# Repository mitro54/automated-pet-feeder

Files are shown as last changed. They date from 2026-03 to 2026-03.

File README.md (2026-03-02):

# automated-pet-feeder
**This is a small personal project running on a Raspberry Pi 1 to allow pet to get some treats while the owner is away.**

The device is made out of 3D printed parts (PLA for all of the container/frame and soft TPU for the rotor to be pet safe) and uses a Raspi 1 to control the feeder. Basicly it uses an old web camera (the slot on the lid is used for mounting it) and a stepper motor to spin a 4 bladed rotor 90 degrees per run, that pushes the treats out of the container, while livestreaming and recording it. The device can be monitored and controlled via a web interface. Due to the limitation of the Raspi 1 performance, the saved "video" of the stream is actually a flipbook of images running on a loop.

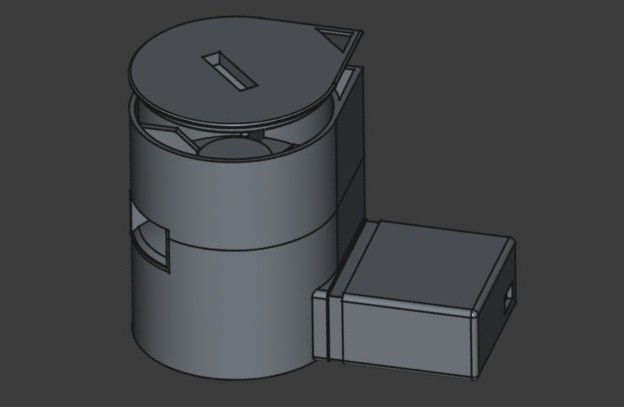
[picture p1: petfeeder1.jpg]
CAD render of the feeder


| Component | Pin Type | RPi Physical Pin | GPIO Number (BCM) |
| :--- | :--- | :--- | :--- |
| **Motor IN1** | Output | Pin 7 | GPIO 4 |
| **Motor IN2** | Output | Pin 11 | GPIO 17 |
| **Motor IN3** | Output | Pin 13 | GPIO 27 |
| **Motor IN4** | Output | Pin 15 | GPIO 22 |
| **LED Transistor Base** | Output | Pin 12 | GPIO 18 (via 1k resistor) |
| **Common Ground** | GND | Pin 6, 9, or 14 | GND |
| **Driver/LED Power** | 5V | Pin 2 or 4 | 5V |

## Setup

Here is a template for my personal setup with this, modify to fit your timezone and paths.

1. Set timezone
`sudo timedatectl set-timezone Europe/Helsinki`

2. Create systemd service
`sudo nano /etc/systemd/system/petfeeder.service`

3. Add the following content to the service file:
```bash
[Unit]
Description=Pet Feeder Controller
After=network.target
[Service]
ExecStart=/usr/bin/python3 /home/user/pet_feeder/controller.py
WorkingDirectory=/home/user/pet_feeder
User=user
Restart=always
RestartSec=5
[Install]
WantedBy=multi-user.target
```

4. Reload systemd and enable the service
`sudo systemctl daemon-reload`
`sudo systemctl enable petfeeder.service`
`sudo systemctl start petfeeder.service`

5. Check status
`sudo systemctl status petfeeder.service`

6. Make feed.sh executable
`chmod +x /home/user/pet_feeder/feed.sh`

7. Add cron job
`crontab -e`

8. Add the following content to the cron job:
```bash
0 18 * * * /home/user/pet_feeder/feed.sh >> /home/user/pet_feeder/scheduled_feeds.log 2>&1
```

9. All set up! The feeder should now run as a service automatically on startup, accessible via your local or public IP and port 8000 (depends on your setup) and the scheduled feed will be triggered at 6 PM every day by default.

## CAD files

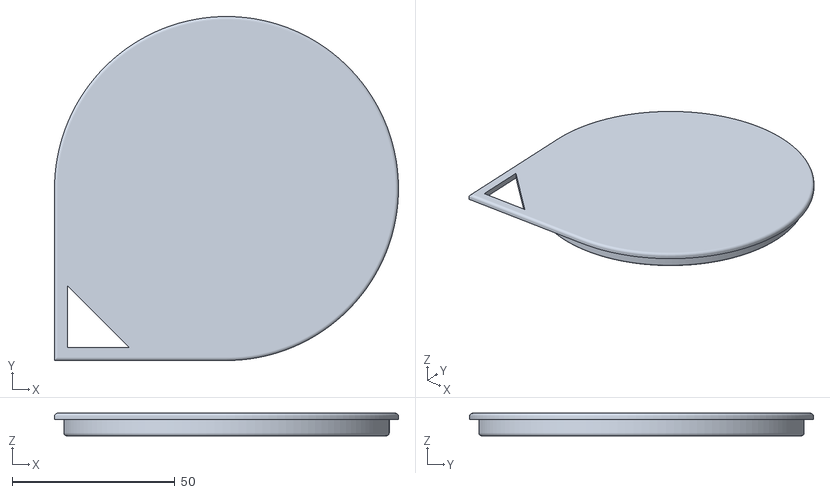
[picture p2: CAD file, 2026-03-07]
syottolaite_v1-lidv2.stl
105.7 x 105.7 x 7.00

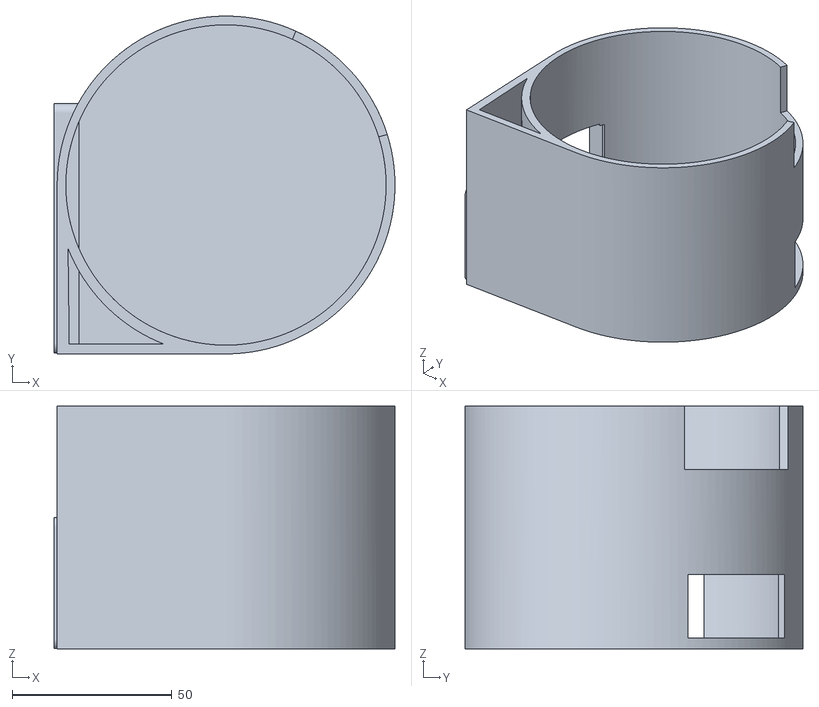
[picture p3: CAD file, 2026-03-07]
syottolaite_v1-body_bottom_Rv2.stl
106.7 x 105.7 x 76.0

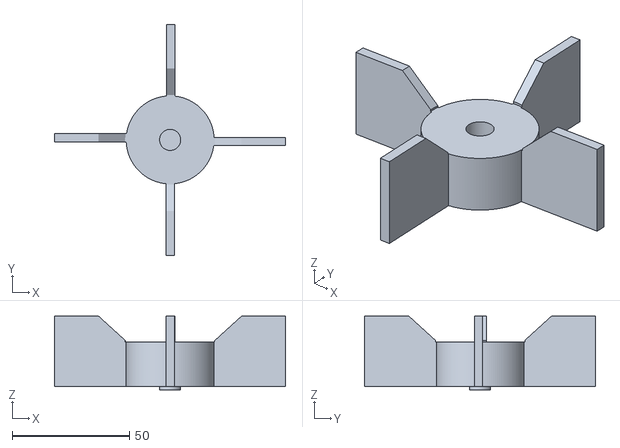
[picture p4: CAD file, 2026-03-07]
syottolaite_v1-rotorv2.stl
98.4 x 98.4 x 31.5

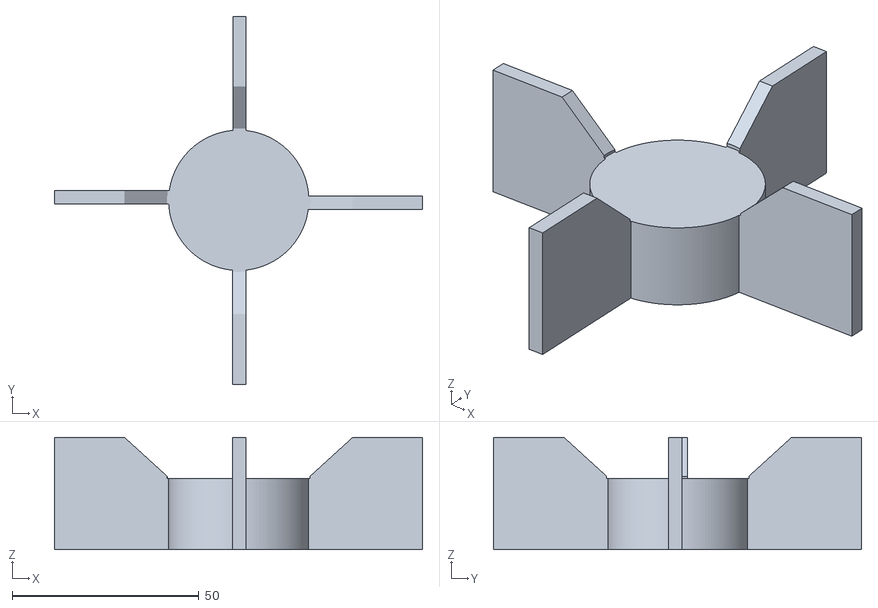
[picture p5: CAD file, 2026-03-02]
syottolaite_v1-rotor.stl
98.4 x 98.4 x 30.0

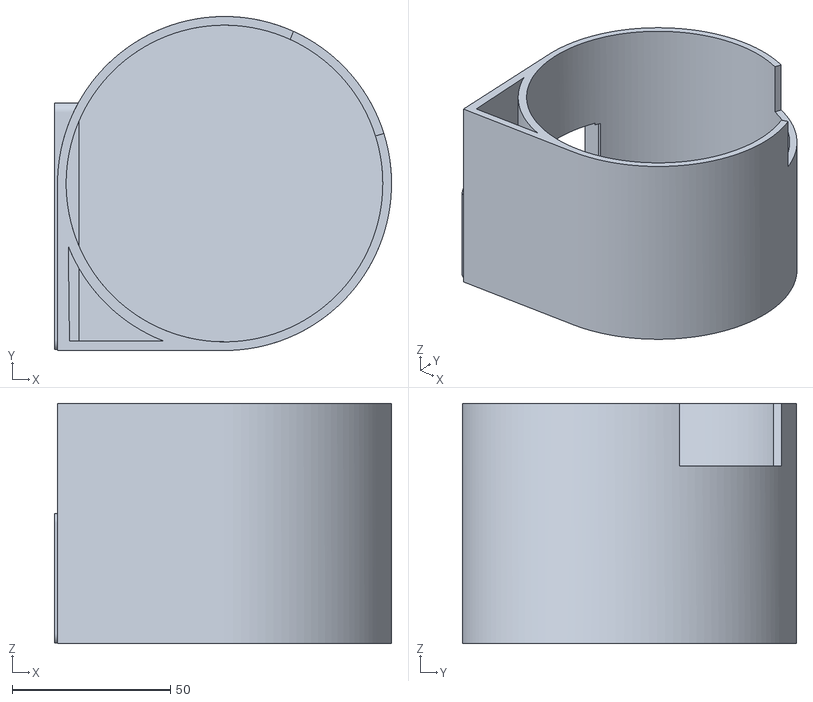
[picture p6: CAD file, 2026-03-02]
syottolaite_v1-body_bottom_R.stl
106.7 x 105.7 x 76.0

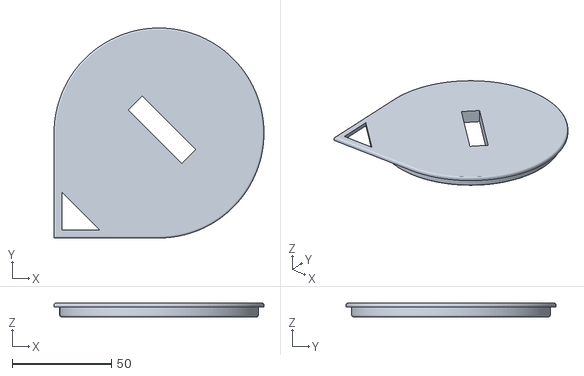
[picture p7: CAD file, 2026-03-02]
syottolaite_v1-lid.stl
105.7 x 105.7 x 7.00

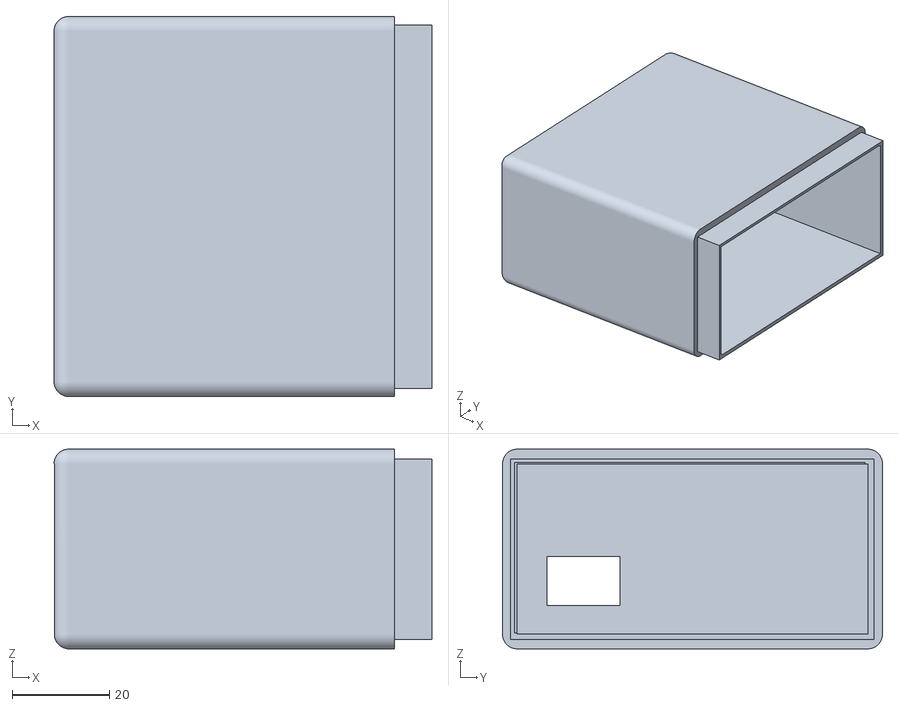
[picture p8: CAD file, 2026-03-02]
syottolaite_v1-body_bottom_L.stl
77.6 x 78.0 x 41.0

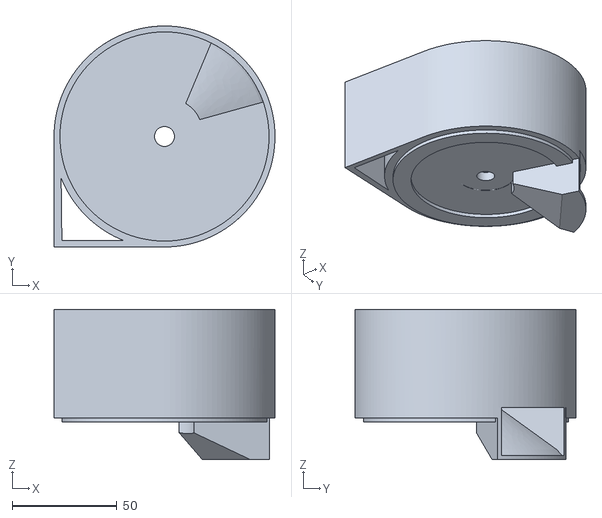
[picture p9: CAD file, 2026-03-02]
syottolaite_v1-body_top.stl
105.7 x 105.7 x 71.9

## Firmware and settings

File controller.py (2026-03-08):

"""Automated pet feeder controller.

Drives a 28BYJ-48 stepper motor (via ULN2003) and an LED indicator
directly from the Raspberry Pi GPIO.  Also serves a web UI for live
camera streaming, recording playback, and manual feed control.
"""

import hashlib
import json
import os
import secrets
import signal
import shutil
import subprocess
import threading
import time
import urllib.request

import RPi.GPIO as GPIO
from http.server import SimpleHTTPRequestHandler, HTTPServer
from socketserver import ThreadingMixIn

# ──────────────────────────────────────────────────────────────────────
# CONFIGURATION
# ──────────────────────────────────────────────────────────────────────

# Stepper motor – 28BYJ-48 via ULN2003 driver board
MOTOR_PINS = [4, 17, 27, 22]       # IN1, IN2, IN3, IN4

# LED indicator – transistor base via 1 kΩ resistor
LED_PIN = 18                        # GPIO 18

# Networking
STREAM_PORT = 8080
WEB_PORT = 8000

# File system
BASE_DIR = os.path.dirname(os.path.abspath(__file__))
STABLE_DIR = os.path.join(BASE_DIR, "stable_run")
TEMP_DIR = os.path.join(BASE_DIR, "temp_recording")
SNAPSHOT_URL = f"http://localhost:{STREAM_PORT}/?action=snapshot"

# Authentication
PIN_FILE = os.path.join(BASE_DIR, ".pin")
SESSION_COOKIE = "feeder_session"

# Hardware commands
STREAM_CMD = (
    f'/usr/local/bin/mjpg_streamer '
    f'-i "input_uvc.so -d /dev/video0 -r 640x480 -f 10" '
    f'-o "output_http.so -p {STREAM_PORT}"'
)

# ──────────────────────────────────────────────────────────────────────
# STEPPER MOTOR DRIVER
# ──────────────────────────────────────────────────────────────────────

# Half-step sequence for the 28BYJ-48 (8 phases per electrical cycle).
# 4096 half-steps = one full revolution (5.625° per step).
HALF_STEP_SEQUENCE = [
    [1, 0, 0, 1],
    [0, 0, 0, 1],
    [0, 0, 1, 1],
    [0, 0, 1, 0],
    [0, 1, 1, 0],
    [0, 1, 0, 0],
    [1, 1, 0, 0],
    [1, 0, 0, 0],
]

STEPS_PER_REVOLUTION = 4096
STEP_DELAY = 0.005 # 5 ms


class StepperMotor:
    """Low-level driver for a 28BYJ-48 stepper motor via ULN2003.

    All public methods are thread-safe through an internal lock.
    """

    def __init__(self, pins: list[int]) -> None:
        if len(pins) != 4:
            raise ValueError("StepperMotor requires exactly 4 GPIO pins.")
        self._pins = pins
        self._lock = threading.Lock()

    # -- public API ----------------------------------------------------

    def rotate(self, degrees: float) -> None:
        """Rotate the motor clockwise by *degrees* (positive only)."""
        if degrees <= 0:
            return
        steps = int(STEPS_PER_REVOLUTION * degrees / 360.0)
        with self._lock:
            self._step(steps)
            self._release()

    def release(self) -> None:
        """De-energise all coils (prevents overheating when idle)."""
        with self._lock:
            self._release()

    # -- internals -----------------------------------------------------

    def _step(self, count: int) -> None:
        seq_len = len(HALF_STEP_SEQUENCE)
        for i in range(count):
            phase = HALF_STEP_SEQUENCE[i % seq_len]
            for pin_index, pin in enumerate(self._pins):
                GPIO.output(pin, phase[pin_index])
            time.sleep(STEP_DELAY)

    def _release(self) -> None:
        for pin in self._pins:
            GPIO.output(pin, GPIO.LOW)


# ──────────────────────────────────────────────────────────────────────
# THREAD-SAFE APPLICATION STATE
# ──────────────────────────────────────────────────────────────────────

state_lock = threading.Lock()


class SystemState:
    """Centralised, thread-safe state for the application."""

    def __init__(self) -> None:
        self.manual_mode: bool = False
        self.manual_stop_requested: bool = False
        self.trigger_feed_requested: bool = False
        self.busy: bool = False


state = SystemState()

# ──────────────────────────────────────────────────────────────────────
# AUTHENTICATION
# ──────────────────────────────────────────────────────────────────────

_pin_hash: str = ""
_valid_sessions: set = set()
_auth_lock = threading.Lock()
_login_attempts: dict = {}  # {ip: [fail_count, lockout_timestamp]}
RATE_LIMIT_MAX = 5
RATE_LIMIT_COOLDOWN = 600  # 10 minutes


def _load_pin() -> None:
    """Load the PIN from .pin file and store its hash."""
    global _pin_hash
    if not os.path.exists(PIN_FILE):
        print("[AUTH] No .pin file found - access control DISABLED.")
        return
    with open(PIN_FILE) as f:
        pin = f.read().strip()
    if not pin.isdigit() or not (4 <= len(pin) <= 6):
        print("[AUTH] PIN must be 4-6 digits. Access control DISABLED.")
        return
    _pin_hash = hashlib.sha256(pin.encode()).hexdigest()
    print("[AUTH] PIN loaded. Access control enabled.")


LOGIN_PAGE = """\
<!DOCTYPE html>
<html lang="en">
<head>
    <meta charset="UTF-8">
    <meta name="viewport" content="width=device-width, initial-scale=1.0">
    <title>Pi Guard - Login</title>
    <style>
        body {
            background: #0d0d0d;
            color: #fff;
            font-family: sans-serif;
            display: flex;
            justify-content: center;
            align-items: center;
            height: 100vh;
            margin: 0;
        }
        .login-box {
            text-align: center;
            padding: 40px;
            background: #1a1a1a;
            border-radius: 10px;
            border: 1px solid #333;
            min-width: 280px;
        }
        h1 { margin: 0 0 8px; font-size: 28px; }
        .subtitle { color: #888; margin: 0 0 24px; font-size: 14px; }
        input {
            padding: 15px;
            font-size: 24px;
            text-align: center;
            letter-spacing: 8px;
            background: #0d0d0d;
            border: 2px solid #333;
            border-radius: 5px;
            color: #fff;
            width: 180px;
            display: block;
            margin: 0 auto;
        }
        input:focus { border-color: #1976d2; outline: none; }
        button {
            display: block;
            margin: 20px auto 0;
            padding: 12px 40px;
            background: #1976d2;
            border: none;
            border-radius: 5px;
            color: #fff;
            font-size: 16px;
            font-weight: bold;
            cursor: pointer;
            width: 100%;
        }
        button:hover { background: #1565c0; }
        .error {
            color: #d32f2f;
            margin-top: 12px;
            font-size: 14px;
            display: none;
        }
    </style>
</head>
<body>
    <div class="login-box">
        <h1>Pi Guard</h1>
        <p class="subtitle">Enter PIN to continue</p>
        <form id="f">
            <input type="password" id="p" maxlength="6"
                   pattern="[0-9]*" inputmode="numeric"
                   placeholder="----" autofocus>
            <button type="submit">Enter</button>
        </form>
        <p class="error" id="e">Wrong PIN</p>
    </div>
    <script>
        document.getElementById('f').onsubmit = async (e) => {
            e.preventDefault();
            const el = document.getElementById('e');
            const inp = document.getElementById('p');
            const r = await fetch('/auth', {
                method: 'POST',
                headers: {'Content-Type': 'application/json'},
                body: JSON.stringify({pin: inp.value})
            });
            if (r.ok) { location.reload(); }
            else if (r.status === 429) {
                el.textContent = 'Too many attempts. Try again in 10 minutes.';
                el.style.display = 'block';
                inp.value = '';
                inp.disabled = true;
                document.querySelector('button').disabled = true;
            } else {
                el.textContent = 'Wrong PIN';
                el.style.display = 'block';
                inp.value = '';
                inp.focus();
            }
        };
    </script>
</body>
</html>
"""

# ──────────────────────────────────────────────────────────────────────
# WEB SERVER
# ──────────────────────────────────────────────────────────────────────


class ThreadedHTTPServer(ThreadingMixIn, HTTPServer):
    """Handle web requests in separate threads to prevent blocking."""

    daemon_threads = True


class WebHandler(SimpleHTTPRequestHandler):
    """Custom handler for the control-panel API and static files."""

    # -- authentication ------------------------------------------------

    def _is_authenticated(self) -> bool:
        """Check for a valid session cookie.  Localhost is always allowed."""
        if not _pin_hash:
            return True
        if self.client_address[0] in ("127.0.0.1", "::1"):
            return True
        cookie_header = self.headers.get("Cookie", "")
        for part in cookie_header.split(";"):
            part = part.strip()
            if part.startswith(f"{SESSION_COOKIE}="):
                token = part[len(SESSION_COOKIE) + 1:]
                return token in _valid_sessions
        return False

    def _serve_login_page(self) -> None:
        """Send the PIN entry page."""
        body = LOGIN_PAGE.encode()
        self.send_response(200)
        self.send_header("Content-Type", "text/html; charset=utf-8")
        self.send_header("Content-Length", str(len(body)))
        self.end_headers()
        self.wfile.write(body)

    # -- logging -------------------------------------------------------

    def log_message(self, format: str, *args) -> None:  # noqa: A002
        try:
            request_line = str(args[0])
            status_code = str(args[1])
            if any(t in request_line for t in (".jpg", "snapshot", "favicon.ico")):
                return
            if "GET / " in request_line and status_code == "304":
                return
            print(f"[WEB] {self.client_address[0]} - {format % args}")
        except Exception:
            pass

    def end_headers(self) -> None:
        """Inject no-cache headers for images and the main page."""
        if self.path.endswith((".jpg", ".html")):
            self.send_header(
                "Cache-Control",
                "no-store, no-cache, must-revalidate",
            )
        super().end_headers()

    # -- request routing -----------------------------------------------

    def do_POST(self) -> None:  # noqa: N802
        """Handle POST requests (authentication only)."""
        try:
            if self.path == "/auth":
                ip = self.client_address[0]
                now = time.time()

                # --- Rate limiting ------------------------------------
                with _auth_lock:
                    if ip in _login_attempts:
                        fails, lockout = _login_attempts[ip]
                        if fails >= RATE_LIMIT_MAX and now < lockout:
                            self.send_response(429)
                            self.end_headers()
                            print(f"[AUTH] Rate limited: {ip}")
                            return
                        if now >= lockout and fails >= RATE_LIMIT_MAX:
                            del _login_attempts[ip]

                length = int(self.headers.get("Content-Length", 0))
                body = self.rfile.read(length).decode()
                data = json.loads(body)
                pin = data.get("pin", "")
                submitted = hashlib.sha256(pin.encode()).hexdigest()

                if submitted == _pin_hash:
                    token = secrets.token_hex(16)
                    _valid_sessions.add(token)
                    with _auth_lock:
                        _login_attempts.pop(ip, None)
                    self.send_response(200)
                    self.send_header(
                        "Set-Cookie",
                        f"{SESSION_COOKIE}={token}; Path=/;"
                        f" HttpOnly; SameSite=Strict",
                    )
                    self.end_headers()
                    print(f"[AUTH] Login OK from {ip}")
                else:
                    with _auth_lock:
                        fails, _ = _login_attempts.get(ip, (0, 0))
                        fails += 1
                        lockout = now + RATE_LIMIT_COOLDOWN if fails >= RATE_LIMIT_MAX else 0
                        _login_attempts[ip] = (fails, lockout)
                    self.send_response(401)
                    self.end_headers()
                    print(
                        f"[AUTH] Failed login from {ip}"
                        f" ({fails}/{RATE_LIMIT_MAX})"
                    )
                return
            self.send_response(404)
            self.end_headers()
        except Exception as exc:
            print(f"[ERR] POST Error: {exc}")

    def do_GET(self) -> None:  # noqa: N802
        try:
            # --- Authentication gate ----------------------------------
            if not self._is_authenticated():
                if self.path == "/auth":
                    pass  # handled by do_POST
                else:
                    self._serve_login_page()
                    return

            with state_lock:
                # Gate action endpoints behind the busy flag.
                # Allow /stop_manual and /trigger_feed through during
                # manual mode — they are interrupt signals, not new
                # actions.
                is_manual_interrupt = (
                    state.manual_mode
                    and self.path in ("/stop_manual", "/trigger_feed")
                )
                if (
                    state.busy
                    and not is_manual_interrupt
                    and self.path in (
                        "/start_manual", "/stop_manual",
                        "/trigger_feed",
                    )
                ):
                    self._conflict()
                    return

                if self.path == "/start_manual":
                    state.manual_mode = True
                    state.manual_stop_requested = False
                    self._ok()
                    return

                if self.path == "/stop_manual":
                    state.manual_stop_requested = True
                    self._ok()
                    return

                if self.path == "/trigger_feed":
                    state.trigger_feed_requested = True
                    if state.manual_mode:
                        state.manual_stop_requested = True
                    print("[SYS] Manual Feed Requested")
                    self._ok()
                    return

                if self.path == "/status":
                    self._send_status()
                    return

            # --- Stream proxy (authenticated) -------------------------
            if self.path == "/stream":
                self._proxy_stream()
                return

            if self.path.startswith("/snapshot"):
                self._proxy_snapshot()
                return

            super().do_GET()

        except (BrokenPipeError, ConnectionResetError):
            pass
        except Exception as exc:
            print(f"[ERR] Web Server Error: {exc}")

    # -- helpers -------------------------------------------------------

    def _ok(self) -> None:
        self.send_response(200)
        self.end_headers()

    def _conflict(self) -> None:
        """Return 409 Conflict when the system is busy."""
        self.send_response(409)
        self.end_headers()

    def _send_status(self) -> None:
        payload = json.dumps({
            "manual_mode": state.manual_mode,
            "busy": state.busy,
        }).encode()
        self.send_response(200)
        self.send_header("Content-Type", "application/json")
        self.send_header("Content-Length", str(len(payload)))
        self.end_headers()
        self.wfile.write(payload)

    # -- stream proxy --------------------------------------------------

    def _proxy_stream(self) -> None:
        """Proxy the MJPEG stream from the local streamer."""
        stream_url = f"http://localhost:{STREAM_PORT}/?action=stream"
        upstream = None
        try:
            upstream = urllib.request.urlopen(stream_url, timeout=5)
            content_type = upstream.headers.get(
                "Content-Type", "multipart/x-mixed-replace"
            )
            self.send_response(200)
            self.send_header("Content-Type", content_type)
            self.send_header("Cache-Control", "no-store")
            self.end_headers()
            while True:
                chunk = upstream.read(4096)
                if not chunk:
                    break
                self.wfile.write(chunk)
        except (BrokenPipeError, ConnectionResetError):
            pass  # Client disconnected
        except Exception:
            try:
                self.send_response(502)
                self.end_headers()
            except Exception:
                pass
        finally:
            if upstream:
                upstream.close()

    def _proxy_snapshot(self) -> None:
        """Proxy a single snapshot from the local streamer."""
        try:
            with urllib.request.urlopen(SNAPSHOT_URL, timeout=2) as resp:
                data = resp.read()
            self.send_response(200)
            self.send_header("Content-Type", "image/jpeg")
            self.send_header("Content-Length", str(len(data)))
            self.send_header("Cache-Control", "no-store")
            self.end_headers()
            self.wfile.write(data)
        except Exception:
            self.send_response(502)
            self.end_headers()


# ──────────────────────────────────────────────────────────────────────
# MAIN SURVEILLANCE / FEEDER SYSTEM
# ──────────────────────────────────────────────────────────────────────
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

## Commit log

2026-02-14 add current state of project
2026-02-14 add current state of code
2026-03-01 Modify logic to handle the motor and led etc
    - Previously had simply arduino that dumbly just executed the logic it was setup with, now uses only the raspberry pi 1 for everything, through this script
2026-03-01 Add busy flag for systemstate to prevent manual issues - Would previously allow users to click manual feed trigger multiple times, now only allows one trigger at a time. - Bugfixes regarding this cha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
    [controller.py]
2026-03-02 Modify to fit for production
    - Modify controller.py to allow the cron usage
    - Add feed.sh script for cron usage
    - Modify index.html to remove now redundant button and dead end points / logic
2026-03-02 Add the stl files
    [syottolaite_v1-body_bottom_L.stl, syottolaite_v1-body_bottom_R.stl, syottolaite_v1-body_top.stl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]
2026-03-07 Fix flipbook replacement
    - Noticed an issue with the flipbook replacement, it is now fixed.
    - Removed redundant code / CSS
    [controller.py]
2026-03-07 Add v2 stl - Added slot for camera, now mounted on the bottom of the feeder, removed the slot now from the lid - Rotor has now more reach since the bottom floor of the top part is quite thick. Expect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
    [syottolaite_v1-body_bottom_Rv2.stl, syottolaite_v1-lidv2.stl, syottolaite_v1-rotorv2.stl]
2026-03-08 Reversed motor spin direction and slowed it down
    [controller.py]
